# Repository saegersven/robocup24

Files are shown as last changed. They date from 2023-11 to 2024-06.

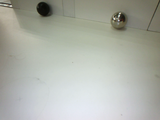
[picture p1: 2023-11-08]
tests/tflite_c_api_test/test_images/2.png

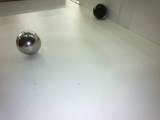
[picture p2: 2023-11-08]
tests/tflite_c_api_test/test_images/4.png

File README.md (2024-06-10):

# robocup24
2024 Repository for Team BitFlip, RoboCup Junior Rescue Line

Previous year's repos:
[2023](https://github.com/saegersven/robocup23)
[2022](https://github.com/saegersven/robocup)

Website: [kraemer123.de](http://kraemer123.de)
YouTube: [EvB Robocup](https://www.youtube.com/@evbrobocup/)

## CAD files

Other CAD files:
cad/Base/Chassis v22.f3d
cad/Base/Motor_Mount v2 v1.f3d
cad/Base/pcb v49.f3d
cad/Front/BNO_Mount v3.f3d
cad/Front/Cam_Servo_Mount v6.f3d
cad/Front/Camera_Mount v24.f3d
cad/Front/Camera_Pivot v57.f3d
cad/Front/Front_Mount v104.f3d
cad/Front/Lens_Bracket v37.f3d
cad/Front/cup v47.f3d
cad/tests and prototyping/Gripper_Half v15.f3d
cad/tests and prototyping/not a trashcan too v102.f3d
cad/top and rear/Handle v3.f3d
cad/top and rear/Rear_Mount v37.f3d
cad/top and rear/VL53L0X_Mount v9.f3d

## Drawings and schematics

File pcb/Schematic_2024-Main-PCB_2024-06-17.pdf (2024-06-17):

## VL53L0X BTN +⁵V

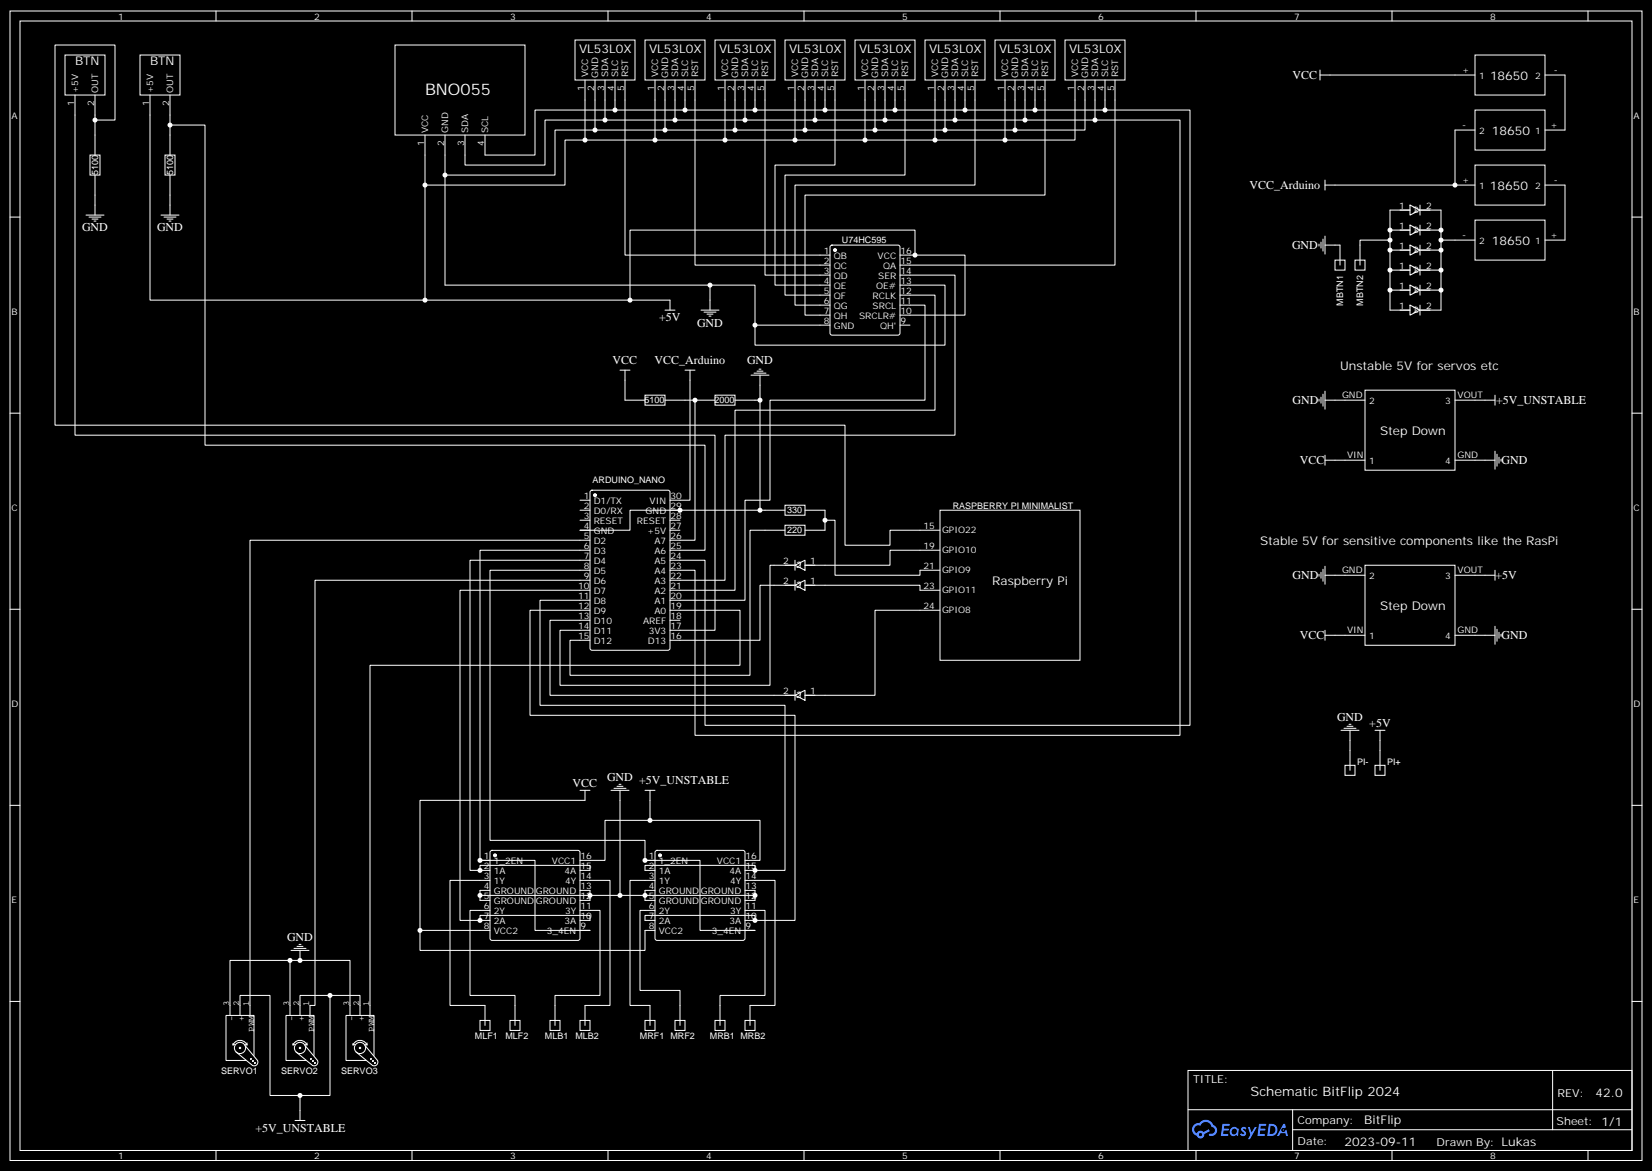
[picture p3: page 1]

SRCLR# 10 SRCL 11 RCLK 12 OE# 13 SER 14 QA 15 VCC 16

Unstable 5V for servos etc

Stable 5V for sensitive components like the RasPi

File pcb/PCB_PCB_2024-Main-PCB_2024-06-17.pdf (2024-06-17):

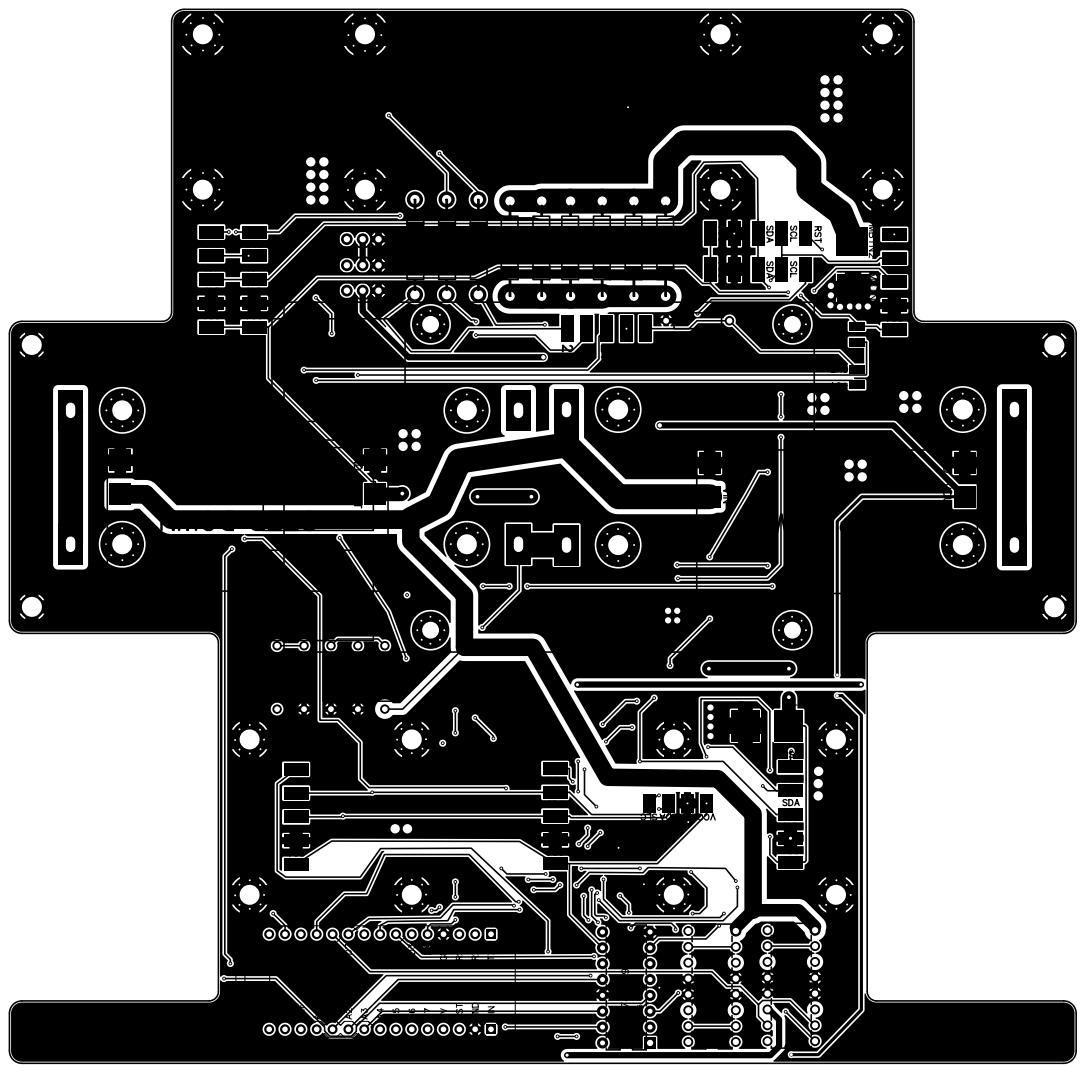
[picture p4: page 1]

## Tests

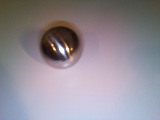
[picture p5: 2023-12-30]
tests/tflite_c_api_test/test.png

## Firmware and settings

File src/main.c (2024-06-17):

#include <stdio.h>
#include <pthread.h>
#include <signal.h>

#include "camera.h"
#include "robot.h"
#include "vision.h"
#include "utils.h"
#include "line/line.h"
#include "rescue/rescue.h"
#include "display/display.h"

#define STATE_LINE 0
#define STATE_RESCUE 1

//#define DISABLE_BUTTON_START
//#define RESCUE_START


static int state;
static pthread_t main_thread_id;

void *main_loop(void *arg) {
    pthread_detach(pthread_self());

    printf("MAIN THREAD START\n");

    // Do all the setup here
#ifndef RESCUE_START
    state = STATE_LINE;
    line_start();
#else
    state = STATE_RESCUE;
#endif
    srand(milliseconds());

    while(1) {
        if(state == STATE_LINE) {
            int ret = line();
            if(ret == 1) {
                printf("Found silver\n");
                state = STATE_RESCUE;
                line_stop();
                delay(200);
            }
        } else {
            rescue();

            // Rescue finished
            state = STATE_LINE;
            line_start();
        }
    }
}

// Reset
void stop() {
    printf("MAIN THREAD CANCEL\n");
    pthread_cancel(main_thread_id);
    pthread_join(main_thread_id, NULL);

    robot_stop();

    // Cleanup a bit (hopefully works)
    if(state == STATE_LINE) {
        line_stop();
    } else if(state == STATE_RESCUE) {
        rescue_cleanup();
    }
    //robot_serial_close();
    //robot_serial_init();

    printf("STOP\n");

#ifdef DISPLAY_ENABLE
    display_set_mode(MODE_IDLE);
#endif
}

void quit() {
    stop();
    display_destroy();

    robot_led(0);

    exit(0);
}

void sig_int_handler(int sig) {
    if(sig == SIGINT) {
        printf("SIGINT\n");
        quit();
    }
}

void button_loop(int button_value, int idle) {
    while((robot_button() ? 1 : 0) == (button_value ? 1 : 0)) {
#ifdef DISPLAY_ENABLE
        if(display_loop()) quit();
        if(idle) {
            display_set_number(NUMBER_BAT_VOLTAGE, robot_sensor(BAT_VOLTAGE));
            delay(20);
        }
#endif
    }
}

int main() {
    if(signal(SIGINT, sig_int_handler) == SIG_ERR) {
        fprintf(stderr, "Can't catch SIGINT\n");
    }

    robot_init();

#ifdef DISPLAY_ENABLE
    display_create(0);
#endif

    while(1) {
#ifndef DISABLE_BUTTON_START
        robot_led(1);
        button_loop(0, 1);
        robot_led(0);
        button_loop(1, 1);
#endif

        pthread_create(&main_thread_id, NULL, main_loop, NULL);

        button_loop(0, 0);

        exit(1);

        stop();

        button_loop(1, 0);
    }
}

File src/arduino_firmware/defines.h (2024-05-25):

#pragma once

#define PI 3.141592653f

// MOTORS
// A and B are pins to control direction
// EN are PWM control pins
#define M_LEFT_A         4
#define M_LEFT_B         7
#define M_LEFT_EN        6

#define M_RIGHT_A        8
#define M_RIGHT_B        9
#define M_RIGHT_EN       5

#define MOTOR_CORRECTION_FACTOR 0.9

#define PIN_BTN             0
#define PIN_BATTERY_VOLTAGE A7

#define REAR_WHEEL_FACTOR 1.1f

#define NUM_SERVOS 3
int servo_pins[NUM_SERVOS] = {3, A0, 2};

Servo servos[NUM_SERVOS];

#define NUM_DIST_SENSORS 3
VL53L0X dist_sensors[NUM_DIST_SENSORS];
int dist_pins[NUM_DIST_SENSORS] = {A1, A2, A3};
byte dist_sensors_addresses[NUM_DIST_SENSORS] = {0x01, 0x02, 0x03};

Adafruit_BNO055 bno = Adafruit_BNO055(55, 0x28);
static float heading, pitch;

#define SENSOR_PITCH 10
#define SENSOR_HEADING 11

#define SENSOR_DIST_START 2
#define SENSOR_DIST_END 4

#define SENSOR_BAT_VOLTAGE 12

// PROTOCOL
#define CMD_MOTOR   (0x01)
#define CMD_SERVO   (0x03)
#define CMD_SENSOR  (0x04)
#define CMD_TURN    (0x05)

#define CMD_LED     (0x06)
#define CMD_BAT_VOLTAGE (0x07)


#define BYTE_TURN_DONE (0x01)
#define MIN_TIME_PER_DEG 4
#define MAX_TIME_PER_DEG 10
#define TURN_TOLERANCE 11


#define CMD_LEN_MOTOR 3
#define CMD_LEN_SERVO 5
#define CMD_LEN_SENSOR 2
#define CMD_LEN_TURN 3
#define CMD_LEN_LED 2

#define MIN_BATTERY_VOLTAGE 11.2f // 4x 3V - 0.8V should trigger alert (0.8V is due to voltage drop accross diodes for reverse voltage protection)

// Message lengths, indexed with command ID. Length including command and data
// Command ID between transfers is zero -> large message length for ID zero
const int message_lengths[7] = {0xFF, CMD_LEN_MOTOR, 0xFF, CMD_LEN_SERVO, CMD_LEN_SENSOR, CMD_LEN_TURN, CMD_LEN_LED};

float start_up_bat_voltage = 0;

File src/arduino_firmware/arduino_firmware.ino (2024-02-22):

/*
  This file contains only SPI setup, message transfer and parsing.
  All robot functionality is in functions.ino.
*/

#include <Servo.h>
#include <EEPROM.h>
#include <VL53L0X.h>
#include <Wire.h>
#include <Adafruit_Sensor.h>
#include <Adafruit_BNO055.h>

#include "defines.h"

#define SERIAL_BUF_SIZE 32

uint8_t message[SERIAL_BUF_SIZE];
int message_pos = 0;

// TODO: add function description
void parse_message() {
  if (message[0] == CMD_MOTOR) {
    //digitalWrite(13, HIGH);
    m(*((int8_t*)&message[1]), *((int8_t*)&message[2]), 0);
  } else if (message[0] == CMD_SERVO) {
    servo(message[1], message[2], message[3], message[4]);
  } else if (message[0] == CMD_SENSOR) {
    int16_t value = -1;

    if (message[1] == SENSOR_PITCH) {
      update_orientation();
      value = (int16_t)(get_pitch() * 1000.0f);
    } else if (message[1] == SENSOR_HEADING) {
      update_orientation();
      value = (int16_t)(get_heading() * 1000.0f);
    } else if (message[1] >= SENSOR_DIST_START && message[1] <= SENSOR_DIST_END) {
      // One of the distance sensors
      int sensor_id = message[1] - SENSOR_DIST_START;
      if (sensor_id < NUM_DIST_SENSORS) {
        value = distance(sensor_id);
      }
    } else if(message[1] == SENSOR_BAT_VOLTAGE) {
      value = get_battery_voltage() * 10;
    }

    Serial.write((uint8_t*)&value, 2);
  } else if (message[0] == CMD_TURN) {
    turn(*((int16_t*)&message[1]));
  } else if (message[0] == CMD_LED) {
    digitalWrite(13, message[1]);
  }
}

void setup() {
  Serial.begin(115200);
  pinMode(13, OUTPUT);
  init_robot();
}

void loop() {

  while (Serial.available() > 0) {
    message[message_pos] = Serial.read();
    message_pos++;

    if (message_pos == SERIAL_BUF_SIZE) {
      message_pos = 0;
    }

    if (message_pos == message_lengths[message[0]]) {
      parse_message();
      message_pos = 0;
      message[0] = 0;
    }
  }
}

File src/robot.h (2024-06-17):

/****************************************************************************************************************
 *                                                                                                              *
 * ROBOT                                                                                                        *
 *                                                                                                              *
 * Controls robot hardware. Provides methods for driving actuators and for reading sensors. Communicates        *
 * with Arduino over SPI (device 0.0). Also reads out GPIO (for start/stop button).                             *
 *                                                                                                              *
 * robot_init()                           - Initialize robot (GPIO and SPI communication)                       *
 * robot_spi_init()                       - Initializes SPI                                                     *
 *                                                                                                              *
 * robot_drive(left, right, duration)     - Sends drive command to Arduino with motor speeds and sends          *
 *                                          stop command after 'duration' milliseconds.                         *
 * robot_stop()                           - Send drive command to Arduino with speed 0.                         *
 * robot_turn(angle)                      - Send turn command to Arduino and wait for turning to finish.        *
 *                                                                                                              *
 * robot_servo(angle, stall)              - Send servo command to Arduino. Setting stall to true lets servo     *
 *                                          stay attached after movement. Setting stall to false detaches       *
 *                                          servo after movement. Angle of zero means no movement.              *
 * robot_button()                         - Returns true if start/stop button is pressed.                       *
 *                                                                                                              *
 * robot_sensor(sensor_id)                - Sends sensor command to Arduino and returns response.               *
 * robot_distance_avg(sensor_id, n, p)    - Reads sensor n times and returns the average of the readings        *
 *                                          in the middle (1 - 2*p)*100 %.                                      *
 *                                                                                                              *
 ****************************************************************************************************************/

#pragma once

#include <stdbool.h>
#include <stdint.h>

#define ARDUINO_BOOT_UP_DELAY 2000

// GPIO Pins
#define PIN_BTN 22 // TODO

// Servo Pins
#define SERVO_CAM 0
#define SERVO_ARM 1
#define SERVO_STRING 2

// Sensor IDs
#define DIST_FRONT      (2)
#define DIST_RIGHT_FRONT (3)
#define DIST_RIGHT_REAR  (4)
#define IMU_PITCH       (10)
#define IMU_YAW         (11) // Yaw/Heading
#define BAT_VOLTAGE     (12)

// Command IDs
#define CMD_MOTOR   (0x01)
#define CMD_SERVO   (0x03)
#define CMD_SENSOR  (0x04)
#define CMD_TURN    (0x05)
#define CMD_LED     (0x06)

#define CAM_HEIGHT_MM 140

#define CAM_POS_UP 60       // 20° to the horizontal
#define CAM_POS_HORIZONTAL 36
#define CAM_POS_DOWN2 90
#define CAM_POS_DOWN3 113
#define CAM_POS_DOWN 138    // 85° to the horizontal

#define ARM_POS_DOWN 136
#define ARM_POS_HALF_DOWN 106

#define ARM_POS_UP 15
#define STRING_POS_CLOSED 130
#define STRING_POS_OPEN 30

#define DISTANCE_FACTOR 0.0f // TODO

#define CAM_HORIZONTAL_FOV DTOR(62.0f)
#define CAM_VERTICAL_FOV DTOR(49.0f)

// millis it takes to turn one rad at 50% speed
// robot_drive(50, -50, MS_PER_RAD) turns one RAD
#define MS_PER_RAD 22

// Initialization
void robot_init();
void robot_serial_init();
void robot_serial_close();
void robot_serial_reset();

void robot_serial_write_command(uint8_t command, uint8_t *data, uint8_t len);
int robot_serial_read(uint8_t *data, uint8_t len);

// Movement
void robot_drive(int8_t left, int8_t right, int32_t duration);
bool robot_stop();
void robot_turn(float angle);
void robot_led(bool state);
void robot_servo(uint8_t servo_id, uint8_t angle, bool stall, bool nodelay);

// Sensing
bool robot_button();

int16_t robot_sensor(uint8_t sensor_id);

int robot_distance_avg(uint8_t sensor_id, int num_measurements, int remove_percentage);

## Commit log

2023-10-19 camera.c and vision.c mostly implemented, also some utils
2023-10-20 Started implementing robot.c. Fully implemented Pi-Side SPI (untested). Started implementing Arduino firmware, implemented SPI (untested) as well as some other functions
2023-10-24 Restructured camera_capture_loop
2023-10-31 battery voltage
2023-10-31 motor test
2023-11-14 Added SPI test
2023-11-20 unsuccessful SPI test
2023-11-26 switched from SPI to USB
2023-12-15 Tested sensor and servo over serial and display on pi
2023-12-27 Changed motor pins
2023-12-30 Green fixes, obstacle, silver, first victim collection tests
    [arduino_firmware.ino, defines.h, functions.ino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]
2024-01-10 fixed distance and silver, added capture script
    [capture.py, functions.ino, line.c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]
2024-02-19 all distance sensors working simultaneously
2024-02-20 distance from Pi not working
    [arduino_firmware.ino, main.c, obstacle.h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]
2024-02-20 battery voltage display
2024-02-20 fixed camera
2024-02-24 fix for broken VL53L0X
    [arduino_firmware.ino, functions.ino, main.c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]
2024-02-29 fixed other distance sensors
    [defines.h, functions.ino]
2024-03-05 fixed side dist from Pi
    [arduino_firmware.ino, main.c, obstacle.h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]
2024-03-06 Implemented exit camera routines
2024-03-06 cam servo not working
    [rescue.c]
2024-03-24 better wall follower, tried to fix exit
    [rescue.c, silver.h, vision.h]
2024-06-13 fixed slow victim approach
    [corner.h, main.c, obstacle.h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]
2024-06-17 added 3d files
    [BNO_Mount v3.f3d, Cam_Servo_Mount v6.f3d, Camera_Mount v24.f3d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]
2024-06-17 added pcb files
